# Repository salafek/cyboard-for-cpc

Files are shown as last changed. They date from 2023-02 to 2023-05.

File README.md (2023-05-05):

# Cyboard for the Amstrad CPC
Cyboard is a [Symbiface II](https://www.cpcwiki.eu/index.php/SYMBiFACE_II) clone with embedded Ethernet controller for the [Amstrad CPC](https://www.cpcwiki.eu/index.php/CPC) range of computers.</br>
Its Ethernet controller is supported by [SymbOS](http://symbos.de) (download the network daemon [here](https://github.com/salafek/Net4CPC/tree/main/Extra)) and by [KCNet utilities](https://github.com/salafek/KCNet-software-for-Net4CPC) for CP/M.</br>
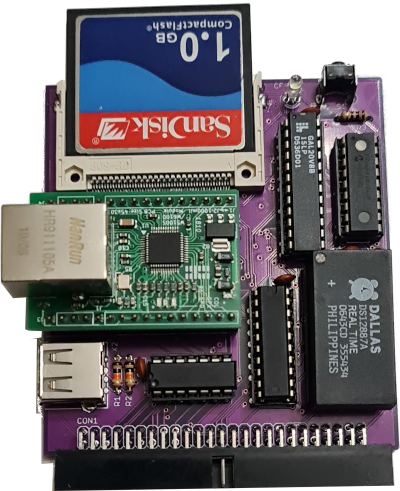
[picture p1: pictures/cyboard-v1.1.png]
Cyboard v1.1

## Interface main components and functions
- Compact Flash Card mass storage device
- PS/2 compatible USB Mouse controller
- Real Time Clock
- Ethernet controller with embedded TCP/IP stack
- Reset button

Unlike Symbiface II, Cyboard doesn't integrate RAM or ROM expansion for the CPC.

All the integrated devices are fully compatible with the original Symbiface II thus using the same [I/O port addresses](https://www.cpcwiki.eu/index.php/SYMBiFACE_II:I/O_Map_Summary).</br>
The interface uses a full 16-bit address decoding. A dual 4-input AND gate 74HCT21 and a GAL20V8 PLD is used for this purpose. All the GAL's outputs are programmed as combinational outputs.</br>
The interface has a [Mother X4](https://cpcrulez.fr/hardware-interface-mother_x4.htm) compatible connector.</br> 
The CF card works in memory mode so it can be directly addressed as an 8-bit device and has no need for initialization via software.</br>
The mouse controller is a [Microchip PIC16F84A](https://www.microchip.com/en-us/product/PIC16F84A) programmed in assembly and it is clocked by the CPCs 4MHz clock. It supports mice with 5 buttons and scroll wheel.</br>
The RTC module is the famous [DS12887](https://www.analog.com/en/products/ds12887.html#product-overview) which is also used in the original Symbiface II.(variants DS12887A, DS12C887, DS12C887A can also be used)</br>
The network module is based on the [WIZnet's W5100S](https://www.wiznet.io/product-item/w5100s/) embedded ethernet controller and works in indirect parallel bus mode.</br>
In this mode it needs 4 I/O ports:
- #FD20: MR - Common Register MR
- #FD21: IDM_ARH - Upper 8 bits Offset Address Register
- #FD22: IDM_ARL - Lower 8 bits Offset Address Register
- #FD23: IDM_DR - 8 Bits Data Register

A detailed description on how to program the module, with flow diagrams and programming examples, can be found at the WIZnet's official site:</br>
[W5100S TCP Function](https://docs.wiznet.io/Product/iEthernet/W5100S/Application-Note/tcp)</br>
[W5100S UDP Function](https://docs.wiznet.io/Product/iEthernet/W5100S/Application-Note/udp)</br>
[SOCKET-less Command](https://docs.wiznet.io/Product/iEthernet/W5100S/Application-Note/socket-less-command)</br>

[The module](https://www.aliexpress.com/w/wholesale-%22W5100S-Network-Module%22-parallel.html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) that's been used in this implementation is one with an integrated 3.3V regulator but also the original WIZnet's [W5100S](https://github.com/Wiznet/Hardware-Files-of-WIZnet/tree/master/05_Network_Module/WIZ810SMJ) and [W6100](https://github.com/Wiznet/Hardware-Files-of-WIZnet/tree/master/05_Network_Module/WIZ610MJ) modules can be used instead, with small changes in the design.</br>

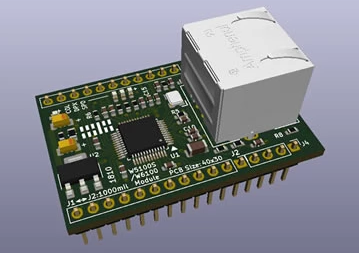
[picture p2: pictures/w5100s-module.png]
W5100S module


## Build info
The schematic and layout were generated with Autodesk EAGLE 9.6.2 free edition</br>
The GAL20V8B files were generated with Atmel WinCupl 5.30.4</br>
The PIC16F84A files were generated with Microchip MPLAB IDE 8.83</br>

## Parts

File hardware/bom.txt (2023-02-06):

Partlist

Part          Value                 Package               Digi-Key PN

C1            .1uF                  C025/C320             399-9871-1-ND
C2            .1uF                  C025/C320             399-9871-1-ND
C3            .1uF                  C025/C320             399-9871-1-ND
C4            .1uF                  C025/C320             399-9871-1-ND
C5            .1uF                  C025/C320             399-9871-1-ND
CF-ACT        LED WHITE DIFFUSED    LED3MM                1516-QBL7IW60D-CW-ND
CF-CARD       N7E50-Q516RB-40       3M-N7E50              3M5455-ND
CON1          CPCBUS                HEADER R/A 50POS      732-5414-ND
D1            1N4148                DO35-7                2368-1N4148-ND
D2            1N4148                DO35-7                2368-1N4148-ND
IC1           PIC16F84AP            DIL18                 PIC16F84A-04I/P-ND
IC2           74HCT21N              DIL14                 296-9262-5-ND
IC3           74HCT244N             DIL20                 296-1610-5-ND
IC4           GAL20V8B              DIL24-3               2156-GAL20V8Z-15QP-ND
IC5           DS12887A              DIL24                 DS12887+-ND
MOUSE         87520-0012BLF         USB-A RCPT TH R/A     609-87520-0012BLF-ND
R1            10K                   0204/0207             MFR-25FRE52-10K-ND
R2            10K                   0204/0207             MFR-25FRE52-10K-ND
R3            100                   0204/0207             MFR-25FRE52-100R-ND
R4            470                   0204/0207             MFR-25FRF52-470R-ND
R5            470                   0204/0207             MFR-25FRF52-470R-ND
R6            470                   0204/0207             MFR-25FRF52-470R-ND
R7            470                   0204/0207             MFR-25FRF52-470R-ND
R8            470                   0204/0207             MFR-25FRF52-470R-ND
R9            470                   0204/0207             MFR-25FRF52-470R-ND
R10           470                   0204/0207             MFR-25FRF52-470R-ND
R11           470                   0204/0207             MFR-25FRF52-470R-ND
R12           0                     Jumper                
R13           0                     Jumper                
RESET         BF-3120               SWITCH TACT SPST-NO   SW407-ND
W5100S-MODULE W5100S-NETWORK-MODULE W5100S-NETWORK-MODULE

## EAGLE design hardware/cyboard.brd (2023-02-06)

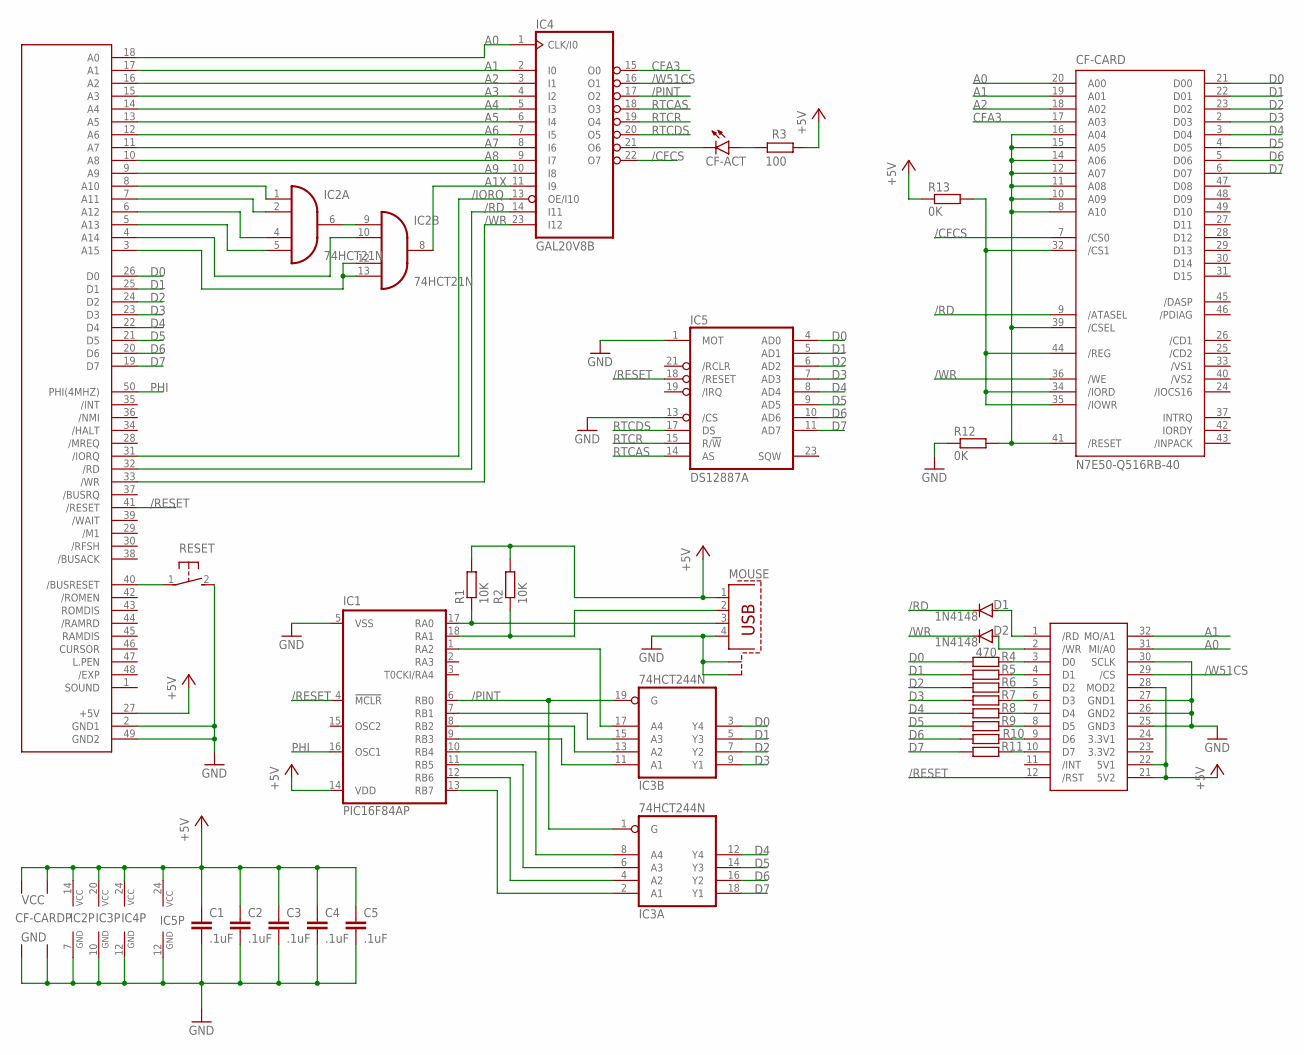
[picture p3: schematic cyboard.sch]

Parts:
C1, C2, C3, C4, C5: .1uF; C025-025X050
CF-ACT: CF ACT; LED3MM
CF-CARD: N7E50-Q516RB-40; 3M-N7E50
CON1: CPCBUS; 2X25
D1, D2: 1N4148; DO35-7
IC1: PIC16F84AP; DIL18
IC2: 74HCT21N; DIL14
IC3: 74HCT244N; DIL20
IC4: GAL20V8B; DIL24-3
IC5: DS12887A; DIL24
MOUSE: PN87520-S
R1, R2: 10K; 0204/7
R3: 100; 0204/7
R4, R5, R6, R7, R8, R9, R10, R11: 470; 0204/7
R12, R13: 0K; 0204/7
RESET: Reset; B3F-31XX
W5100S-MODULE: W5100S-NETWORK-MODULE

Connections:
3.3V1: W5100S-MODULE.24 (3.3V1)
3.3V2: W5100S-MODULE.23 (3.3V2)
/BUSRESET: CON1.40 (/BUSRESET), RESET.1
/CFACT: CF-ACT.K (C), IC4.21 (O6)
/CFCS: CF-CARD.7 (/CS0), IC4.22 (O7)
/IORQ: CON1.31 (/IORQ), IC4.13 (OE/I10)
/PINT: IC1.6 (RB0), IC3.1 (G), IC3.19 (G), IC4.17 (O2)
/RD: CF-CARD.9 (/ATASEL), CON1.32 (/RD), D1.C, IC4.14 (I11)
/RESET: CON1.41 (/RESET), IC1.4 (!MCLR), IC5.18 (/RESET), W5100S-MODULE.12 (/RST)
/W51CS: IC4.16 (O1), W5100S-MODULE.29 (/CS)
/W51RD: D1.A, W5100S-MODULE.1 (/RD)
/W51WR: D2.A, W5100S-MODULE.2 (/WR)
/WR: CF-CARD.36 (/WE), CON1.33 (/WR), D2.C, IC4.23 (I12)
A0: CF-CARD.20 (A00), CON1.18 (A0), IC4.1 (CLK/I0), W5100S-MODULE.31 (MI/A0)
A1: CF-CARD.19 (A01), CON1.17 (A1), IC4.2 (I0), W5100S-MODULE.32 (MO/A1)
A1X: IC2.8 (O), IC4.11 (I9)
A2: CF-CARD.18 (A02), CON1.16 (A2), IC4.3 (I1)
A3: CON1.15 (A3), IC4.4 (I2)
A4: CON1.14 (A4), IC4.5 (I3)
A5: CON1.13 (A5), IC4.6 (I4)
A6: CON1.12 (A6), IC4.7 (I5)
A7: CON1.11 (A7), IC4.8 (I6)
A8: CON1.10 (A8), IC4.9 (I7)
A9: CON1.9 (A9), IC4.10 (I8)
A10: CON1.8 (A10), IC2.1 (I0)
A11: CON1.7 (A11), IC2.2 (I1)
A12: CON1.6 (A12), IC2.4 (I2)
A13: CON1.5 (A13), IC2.5 (I3)
A14: CON1.4 (A14), IC2.10 (I1)
A15: CON1.3 (A15), IC2.12 (I2), IC2.13 (I3)
CFA3: CF-CARD.17 (A03), IC4.15 (O0)
CFDN: CF-CARD.8 (A10), CF-CARD.10 (A09), CF-CARD.11 (A08), CF-CARD.12 (A07), CF-CARD.14 (A06), CF-CARD.15 (A05), CF-CARD.16 (A04), CF-CARD.39 (/CSEL), CF-CARD.41 (/RESET), R12.2
CFUP: CF-CARD.32 (/CS1), CF-CARD.34 (/IORD), CF-CARD.35 (/IOWR), CF-CARD.44 (/REG), R13.2
D0: CF-CARD.21 (D00), CON1.26 (D0), IC3.3 (Y4), IC5.4 (AD0), R4.1
D1: CF-CARD.22 (D01), CON1.25 (D1), IC3.5 (Y3), IC5.5 (AD1), R5.1
D2: CF-CARD.23 (D02), CON1.24 (D2), IC3.7 (Y2), IC5.6 (AD2), R6.1
D3: CF-CARD.2 (D03), CON1.23 (D3), IC3.9 (Y1), IC5.7 (AD3), R7.1
D4: CF-CARD.3 (D04), CON1.22 (D4), IC3.12 (Y4), IC5.8 (AD4), R8.1
D5: CF-CARD.4 (D05), CON1.21 (D5), IC3.14 (Y3), IC5.9 (AD5), R9.1
D6: CF-CARD.5 (D06), CON1.20 (D6), IC3.16 (Y2), IC5.10 (AD6), R10.1
D7: CF-CARD.6 (D07), CON1.19 (D7), IC3.18 (Y1), IC5.11 (AD7), R11.1
GND: C1.2, C2.2, C3.2, C4.2, C5.2, CF-CARD.1 (GND1), CF-CARD.50 (GND2), CON1.2 (GND1), CON1.49 (GND2), IC1.5 (VSS), IC2.7 (GND), IC3.10 (GND), IC4.12 (GND), IC5.1 (MOT), IC5.12 (GND), IC5.13 (/CS), MOUSE.4, MOUSE.S1, MOUSE.S2, R12.1, RESET.2 (S), W5100S-MODULE.25 (GND3), W5100S-MODULE.26 (GND2), W5100S-MODULE.27 (GND1), W5100S-MODULE.30 (SCLK)
MOUSED0: IC1.1 (RA2), IC3.17 (A4)
MOUSED1: IC1.7 (RB1), IC3.15 (A3)
MOUSED2: IC1.8 (RB2), IC3.13 (A2)
MOUSED3: IC1.9 (RB3), IC3.11 (A1)
MOUSED4: IC1.10 (RB4), IC3.8 (A4)
MOUSED5: IC1.11 (RB5), IC3.6 (A3)
MOUSED6: IC1.12 (RB6), IC3.4 (A2)
MOUSED7: IC1.13 (RB7), IC3.2 (A1)
unnamed: CF-ACT.A, R3.2
unnamed: IC2.6 (O), IC2.9 (I0)
PHI: CON1.50 (PHI(4MHZ)), IC1.16 (OSC1)
RTCAS: IC4.18 (O3), IC5.14 (AS)
RTCDS: IC4.20 (O5), IC5.17 (DS)
RTCR: IC4.19 (O4), IC5.15 (R/!W)
USBD+: IC1.17 (RA0), MOUSE.3, R1.1
USBD-: IC1.18 (RA1), MOUSE.2, R2.1
VCC: C1.1, C2.1, C3.1, C4.1, C5.1, CF-CARD.13 (VCC2), CF-CARD.38 (VCC1), CON1.27 (+5V), IC1.14 (VDD), IC2.14 (VCC), IC3.20 (VCC), IC4.24 (VCC), IC5.24 (VCC), MOUSE.1, R1.2, R2.2, R3.1, R13.1, W5100S-MODULE.21 (5V2), W5100S-MODULE.22 (5V1), W5100S-MODULE.28 (MOD2)
W51D0: R4.2, W5100S-MODULE.3 (D0)
W51D1: R5.2, W5100S-MODULE.4 (D1)
W51D2: R6.2, W5100S-MODULE.5 (D2)
W51D3: R7.2, W5100S-MODULE.6 (D3)
W51D4: R8.2, W5100S-MODULE.7 (D4)
W51D5: R9.2, W5100S-MODULE.8 (D5)
W51D6: R10.2, W5100S-MODULE.9 (D6)
W51D7: R11.2, W5100S-MODULE.10 (D7)

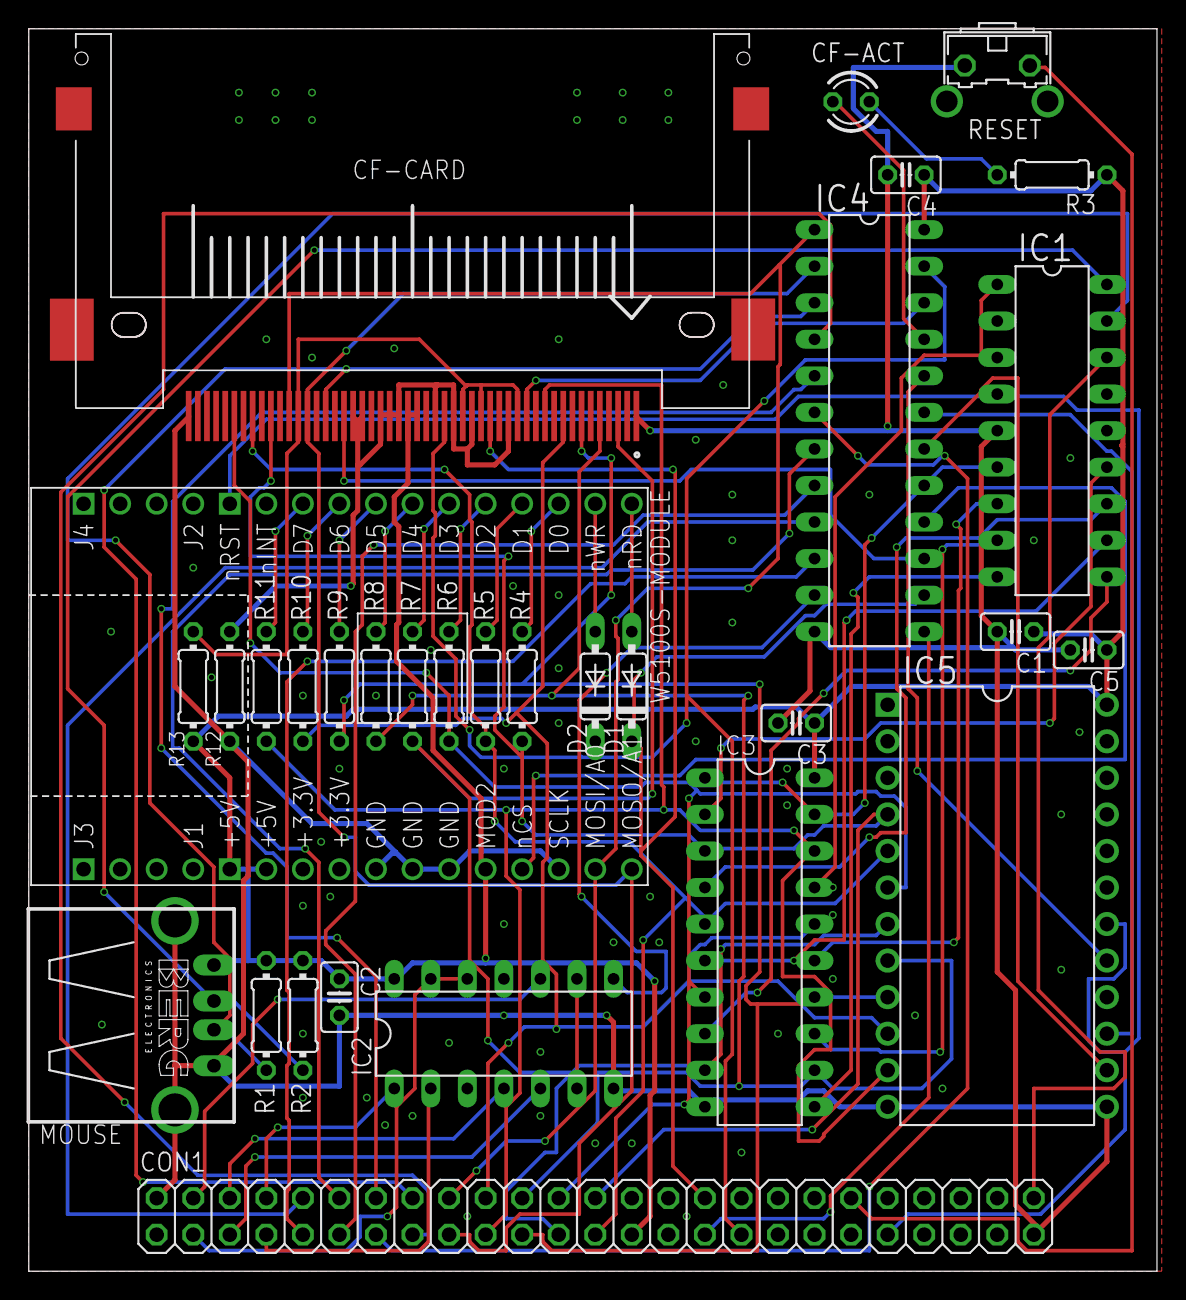
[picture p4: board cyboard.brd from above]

Board: 2 copper layers, 78.4 x 86.4 mm, 31 parts (0 on the bottom side), 65 nets.

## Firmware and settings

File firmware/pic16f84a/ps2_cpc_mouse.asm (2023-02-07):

; -----------------------------------------------
;  PS/2 Mouse to CPC Symbiface II Mouse Converter
; -----------------------------------------------
;  Copyright (C) 2023 Dimitris Kefalas
;  Version: V1.0 (7-Feb-2023)
;  
;  Based on "PS/2 Mouse to Amiga Mouse Converter" by Nevenko Baričević

;  This program is free software: you can redistribute it and/or modify
;  it under the terms of the GNU General Public License as published by
;  the Free Software Foundation, either version 3 of the License, or
;  (at your option) any later version.

;  This program is distributed in the hope that it will be useful,
;  but WITHOUT ANY WARRANTY; without even the implied warranty of
;  MERCHANTABILITY or FITNESS FOR A PARTICULAR PURPOSE.  See the
;  GNU General Public License for more details.

;  You should have received a copy of the GNU General Public License
;  along with this program.  If not, see <http://www.gnu.org/licenses/>.
	list    p=p16f84a
	#include <p16f84a.inc>
	
	__CONFIG   _CP_OFF & _WDT_OFF & _PWRTE_ON & _RC_OSC	

; ---------- registers definition -----------

byte    equ     0x0c		; byte to receive or send
parity  equ     0x0d		; parity bit is held here
parcnt  equ     0x0e		; counter for calculating parity
roller  equ     0x0f		; help for 8 data bits to byte conversion
devid	equ	0x10		; mouse device id
mkeys   equ     0x11		; 1st byte of mouse data packet
xpos    equ     0x12		; 2nd byte of mouse data packet
ypos    equ     0x13		; 3rd byte of mouse data packet
zpos	equ	0x14		; 4th byte of mouse data packet
count   equ     0x15		; packet counter
delcnt  equ     0x16		; delay counter
rkeys   equ     0x17		; real key status
okeys   equ     0x18		; old real key status

; --------- entry point -----------

	org     0
		
	goto	main

; --------- interrupt service routine -----------
	org	4
		
	movf    count,W
	xorlw   0x00		; if count is 00 read mouse
	btfsc   STATUS,Z
	goto    RD_M
	movf    count,W
	xorlw   0x01		; if count is 01 set port b to xpos
	btfsc   STATUS,Z
	goto    SETX
	movf    count,W
	xorlw   0x02		; if count is 02 set port b to ypos
	btfsc   STATUS,Z
	goto    SETY
	movf    count,W
	xorlw   0x03		; if count is 03 set port b to zpos
	btfsc   STATUS,Z
	goto	ZSET
	goto	SETK		; if count is 04 set port b to mkeys

RD_M:   clrf	PORTB		; set mouse data to 0
	bcf	PORTA,2
	incf    count		; packet counter = 01		
	movlw   0xeb		; "Read Data " command to mouse
	call    SENDCMD
	call    REC		; receive byte1 from mouse packet
	call    INHIB
	movf    byte,W
	movwf   mkeys
	andlw	0x07		; get real keys status
	iorlw	0xc0
	movwf	rkeys
	call    REL
	call    REC		; receive byte2 from mouse packet
	call    INHIB
	movf    byte,W
	movwf   xpos
	call    REL
	call    REC		; receive byte3 from mouse packet
	call    INHIB
	movf    byte,W
	movwf   ypos
	call    REL
	movfw	devid		; test if mouse supports 4th byte
	xorlw	0x00
	btfsc	STATUS,Z
	;goto	GOON
	goto    SETX
	call    REC		; receive byte4 from mouse packet
	call    INHIB
	movf    byte,W
	movwf   zpos
	call    REL
	movfw	devid		; test if mouse supports 4th, 5th button
	xorlw	0x04
	btfsc	STATUS,Z
	goto	GOON
	btfsc	zpos,4
	bsf	rkeys,3
	btfsc	zpos,5
	bsf	rkeys,4
	;goto	GOON

SETX:   incf	count 
	movf    xpos,W	
	andlw   0xff		; if xpos=0 go to ypos
	btfsc   STATUS,Z
	goto    SETY
	movf    xpos,W		; set portb to 01(xpos)
	btfsc   mkeys,4		; check if move to right or left
	goto	SETX2
	andlw   0xe0		; check if x overflow right
	btfss   STATUS,Z
	goto    SETX3
	movf    xpos,W
	andlw	0x1f
	iorlw	0x40
	goto    SETX1
SETX3:  movlw   0x5f
	goto    SETX1
SETX2:	andlw   0xe0		; check if x overflow left
	xorlw   0xe0
	btfsc   STATUS,Z
	goto    SETX4
	movlw   0x60
	goto    SETX1
SETX4:  movf    xpos,W
	andlw	0x1f
	iorlw	0x60
SETX1:  movwf   PORTB
	bcf	PORTA,2		; lsb is PORTA bit 2
	btfsc	xpos,0
	bsf	PORTA,2
	goto	GOON

SETY:   incf	count 
	movf    ypos,W	
	andlw   0xff		; if ypos=0 go to zset
	btfsc   STATUS,Z
	goto    ZSET
	movf    ypos,W		; set portb to 10(xpos)
	btfsc   mkeys,5		; check if move to up or down
	goto	SETY2
	andlw   0xe0		; check if y overflow up
	btfss   STATUS,Z
	goto    SETY3
	movf    ypos,W
	andlw	0x1f
	iorlw	0x80
	goto    SETY1
SETY3:  movlw   0x9f
	goto    SETY1
SETY2:	andlw   0xe0		; check if y overflow down
	xorlw   0xe0
	btfsc   STATUS,Z
	goto    SETY4
	movlw   0xa0
	goto    SETY1
SETY4:  movf    ypos,W
	andlw	0x1f
	iorlw	0xa0
SETY1:  movwf   PORTB
	bcf	PORTA,2		; lsb is PORTA bit 2
	btfsc	ypos,0
	bsf	PORTA,2
	goto	GOON

ZSET:	incf	count
	movf    zpos,W	
	andlw   0x0f		; if zpos=0 go to mkeys
	btfsc   STATUS,Z
	goto    SETK
	movf	zpos,W
	andlw	0x0f
	xorlw   0x0f		; 2's complement
	addlw   0x01		;
	iorlw	0xe0
	movwf	PORTB
	bcf	PORTB,4		; expand sign bit
	btfss	zpos,3
	bsf	PORTB,4
	bcf	PORTA,2		; lsb is PORTA bit 2
	btfsc	zpos,0
	bsf	PORTA,2
	goto	GOON

SETK:   clrf	count
	movf	okeys,W		; check if keys status has changed
	xorwf	rkeys,W
	btfsc	STATUS,Z
	goto	RD_M
	movfw   rkeys		; set portb to 11000kkk
	movwf	okeys		; set old keys status = real keys status
	movwf   PORTB
	bcf	PORTA,2		; lsb is PORTA bit 2
	btfsc	rkeys,0
	bsf	PORTA,2 

GOON:  	bcf     INTCON,INTF     ;INTF - clear int flag
	retfie			; return from int

;---------------------- main routine -------------------

main:   bsf     STATUS,RP0	; page 1
	bsf     TRISA,0		; port A, bit 0 is input
	bsf     TRISA,1		; port A, bit 1 is input
	bcf     TRISA,2		; port A, bit 2 is output - lsb of mouse -
	clrf    TRISB		; port B is all outputs
	bsf     TRISB,0		; port B, bit 0 is input - interrupt -
	bcf     STATUS,RP0	; page 0
	clrf    PORTB		; port B all pins to 0
	bcf	PORTA,2		; port A pin 2 to 0
	clrf    count		; packet counter = 00
	movlw   0xc0
	movwf	rkeys		; real keys status = 11000000
	movwf	okeys		; old real keys status = 11000000

	movlw   0xff		; "Reset" command to mouse
	call    SENDCMD
		
	call    REC		; receive byte from mouse	
	call    INHIB		; pull CLK low to inhibit furhter sending	
	movf    byte,W
	xorlw   0xaa		; if it's $AA mouse self test passed
	btfss   STATUS,Z
	goto    IERROR
	call    REL		; release CLK (allow mouse to send)
	call    REC		; receive byte from mouse
	call    INHIB
	movf    byte,W
	xorlw   0x00		; mouse ID code should be $00
	btfss   STATUS,Z
	goto    IERROR
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

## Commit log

2023-02-05 new file: firmware/gal20v8b/Cyboard.jed new file: firmware/gal20v8b/Cyboard.pld new file: firmware/pic16f84a/ps2_cpc_mouse.asm new file: firmware/pic16f84a/ps2_cpc_mouse.hex new file: hardware/cpc_rc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
    [cpc_rct_mouse.brd, cpc_rct_mouse.sch]
2023-02-05 first release renamed: firmware/gal20v8b/Cyboard.jed -> firmware/gal20v8b/cyboard.jed renamed: firmware/gal20v8b/Cyboard.pld -> firmware/gal20v8b/cyboard.pld renamed: hardware/cpc_rct_mouse.brd -> ha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
    [cyboard.brd, cyboard.sch]
